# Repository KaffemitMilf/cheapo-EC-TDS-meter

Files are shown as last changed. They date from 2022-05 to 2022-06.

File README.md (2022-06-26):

# cheapo-EC-TDS-meter

Hey, this is my version of Micheal Rattcliffe´s 3$ EC - PPM Meter. 
His meter is way better engineered than mine, so if you are looking for the most accurate, best build EC/TDS-meter go for his version.
It´s good enough for me/ my hydroponic nft system.

https://hackaday.io/project/7008-hacking-the-way-to-growing-food/log/24646-three-dollar-ec-ppm-meter-arduino

## problem
The electric plugs I used corroded everytime, so I designed a 3D-model, where I inserted two stainless steel rods and a DS18B20.

## working principle 

### units & more
EC - electrical conductivity equals 1/R (R-resistance) and is measured in Siemens - S<br/>
I like to use μS which equals S*10^<sup>−6</sup>, so it is easier to read.

Because the EC depends on the distance between the rods, we want to standarize it, so we use EC/cm or μS/cm.

### measuring the resistance 
To measure the resistance of the water, we use a simple voltage divider, the Arduino can only measure voltage but not resistance.
To get around that, we use a voltage divider, so we can measure a voltage and calculate the resistance.

2a379f0b-66db-470f-b54a-1d5732d96486
(simple voltage divider)

- R<sub>1</sub>resistor (R<sub>1</sub>) - known resistance
- R<sub>2</sub> resistor (R<sub>2</sub>) - unknown resistor, resistance accross the stainless steel rods, water
- V<sub>in</sub> - input voltage
- V<sub>out</sub> - measured voltage across R<sub>2</sub>  

R<sub>2</sub> = (V<sub>out</sub>*R<sub>1</sub>)/ (V<sub>in</sub>-V<sub>out</sub>) (voltage divider formula)

Since our rods are 0.6cm away from each other, we divide the Resistance by 0.6, so we get the resistance for one centimeter <br/>
R<sub>cm</sub> =  R<sub>2</sub>/0.6

### calculating EC 

Calculating the EC/cm and multiplying it by 10<sup>6</sup> to get μS/cm: <br/>
EC<sub>cm</sub> = 1/R<sub>cm</sub>*10<sup>6</sup>

Because the EC depends on the water temperature we need to compensate the temperature, to compare, we use the EC at 25°C: </br>
EC<sub>25</sub> = EC /( 1 + a (T - 25))

- T - temperature of the solution in 0.019°C (measured with the DS18B20)
- a - 0.019 °C (commonly used for nutrient solutions)

dont ask me how and why it works, it is completly stolen from Micheal Ratcliffe´s project...

### avoiding polarization
Although we are using a voltage divider, we cant turn it on for more than a few microseconds at a time as electrolysis begins and gives us wrong readings,  as bubbles form on the probe faces. We turn it on quickly take a measurement and turn it off again before the bubbles have time to form.

## 3D Model
I have no experience, what belongs to 3D printing, so I am only explaining my concept  

You need:
- 2mm diameter stainless steel rods
- DS18B20
- soldering iron
- solder
- some cable
- the 3D print

1. solder a cable to one of the ends of each rod
2. insert the DS18B20 and the steel roods, so it looks like this:
 
stick_view

3. If you want it to be floating, you can fill the gaps with styropor by pressing the 3D-model into it, dont forget to glue it down
4. You can add two strings through these holes, so it is always floating at the same place, I kept the strings under tension by adding a suction cup connected with one end of the string to the bottom of the reservoir and connected the other end to the lid of my hydroponic reservoir.

front_view

## wiring

wiring-removebg-preview

## notes
- use a higher voltage at the V<sub>in</sub> pin than 5V, so the voltage regulator will output 5V as close as possible, otherwise the readings wont be correct
(I used 9V, because I heard of people destroying the voltage regulator using a voltage greater than 9V)
- never plug something directly into the mains!!!
- feel free to ask/ criticize

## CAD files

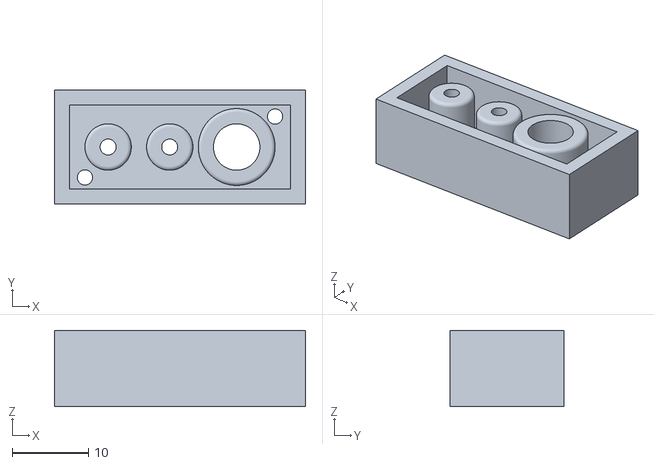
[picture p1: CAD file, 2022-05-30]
3D-model/electrode-DS18B20_holder.stl
33.0 x 15.0 x 10.0

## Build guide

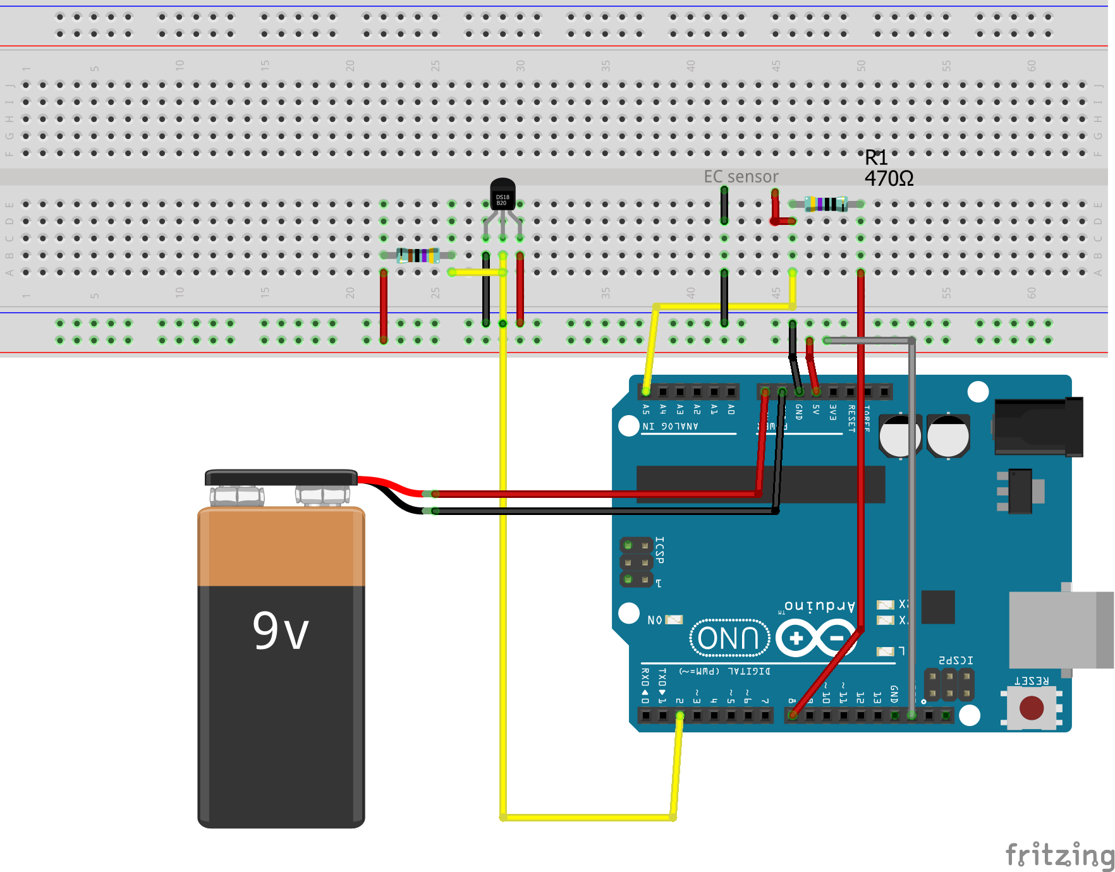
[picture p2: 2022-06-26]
wiring/wiring.png

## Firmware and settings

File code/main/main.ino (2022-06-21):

#include <OneWire.h> 
#include <DallasTemperature.h>

#define ONE_WIRE_BUS 2


OneWire oneWire(ONE_WIRE_BUS);
DallasTemperature sensors(&oneWire);

void setup() {
  Serial.begin(9600);
  delay(1000);  //added to give the onewire stuff time to initialize.
  sensors.begin();

  pinMode(8, OUTPUT);
  analogReference(EXTERNAL);
  
}

void loop() {
  Serial.println("-----------------------------------------");
  Serial.println(String(measureEC()) + "μS");
  delay(10000);
  Serial.println("-----------------------------------------");
}
  


float measureEC(){
  //turn on pin 8
  digitalWrite(8, HIGH);
  delay(500);
 
  
  // measure R2
  int unconvertedReading = analogRead(A5);
  unconvertedReading = analogRead(A5);
  
  //turn off pin 8
  digitalWrite(8, LOW);

  //convert Reading into voltage
  float voltage = (5.0f/1023.0f)*unconvertedReading;

  
  // your r1 value
  int r1 = 470;
  //calculating r2, 
  float r2 = (voltage* r1)/(5.0f-voltage);
  Serial.println(String(r2)+"R2");
  //resistance per cm
  float rCm = (r2/0.6);
 
  //calculate ec/cm 
  float ec = (1.0f/rCm);

  //measure temperature
  float temp = measureTemp();

  
  //compensate temperature
  float ec25 = ec / (1.0f + 0.019f * (temp - 25.0));
  ec25 = ec25* pow(10,6);
  //μS
  
  return ec25;
}



float measureTemp() {
  sensors.requestTemperatures(); //needed, cause otherwise temperature conversion wont take place
  return sensors.getTempCByIndex(0);
}

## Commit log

2022-06-23 wiring diagram
    [wiring.fzz]
2022-06-26 added new wiring diagram png
